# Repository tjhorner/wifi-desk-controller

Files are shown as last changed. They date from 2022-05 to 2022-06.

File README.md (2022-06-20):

# WiFi Desk Controller

This repository includes the source files for my WiFi Desk Controller design.

- `firmware`: The stock ESPHome-based firmware that's available from the GitHub Releases and [my website](https://shop.horner.tj/things/desk-controller/setup/stock)
- `enclosure`: Fusion 360 source, STL, and STEP files for the 3D-printable enclosure
- `pcb`: KiCad project files for the PCB

You may also find the associated [ESPHome custom component](https://github.com/tjhorner/esphome-standing-desk) interesting if you want to implement your own desk brand, or just dive deeper into how the firmware works.

## Stock Firmware

The stock firmware is ESPHome-based, and contains a bunch of components that are useful for setup. It exposes these entities:

- Desk Height: reports desk height as reported by control box
- Target Desk Height: changes the target desk height
- Desk Preset 1: sets the desk height to preset 1
- Desk Preset 2: sets the desk height to preset 2
- Desk Preset 3: sets the desk height to preset 3
- Desk Preset 4: sets the desk height to preset 4

The stock firmware is automatically built for each supported desk on release. There is a [GitHub Actions workflow](.github/workflows/build.yaml) which handles this. The `make-stock-bin` script replaces the `DESK_BRAND` in the [stock config.yaml](firmware/config.yaml) with the appropriate config and builds it. It runs this script for each of the supported desk brands in the build matrix, then uploads a release artifact.

If you would like to contribute compatibility for a new desk, you first need to submit a pull request to [this repo](https://github.com/tjhorner/esphome-standing-desk/tree/master/configs/desks) which adds a config file for the desk (and, if necessary, a new protocol decoder for it). See [Desk Compatibility](https://github.com/tjhorner/wifi-desk-controller/wiki/Desk-Compatibility) for more info on adding a new desk brand.

## License

The ESPHome configs are licensed under MIT; everything else (enclosure and PCB design) are CC BY-NC-SA 4.0. The appropriate license files are available in the root of the repo.

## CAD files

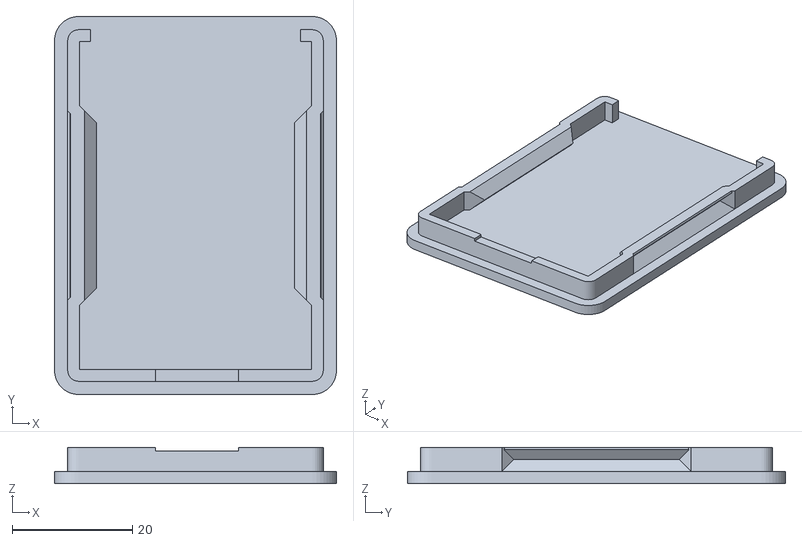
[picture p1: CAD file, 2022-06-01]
enclosure/enclosure_cover.stl
47.0 x 63.0 x 6.00

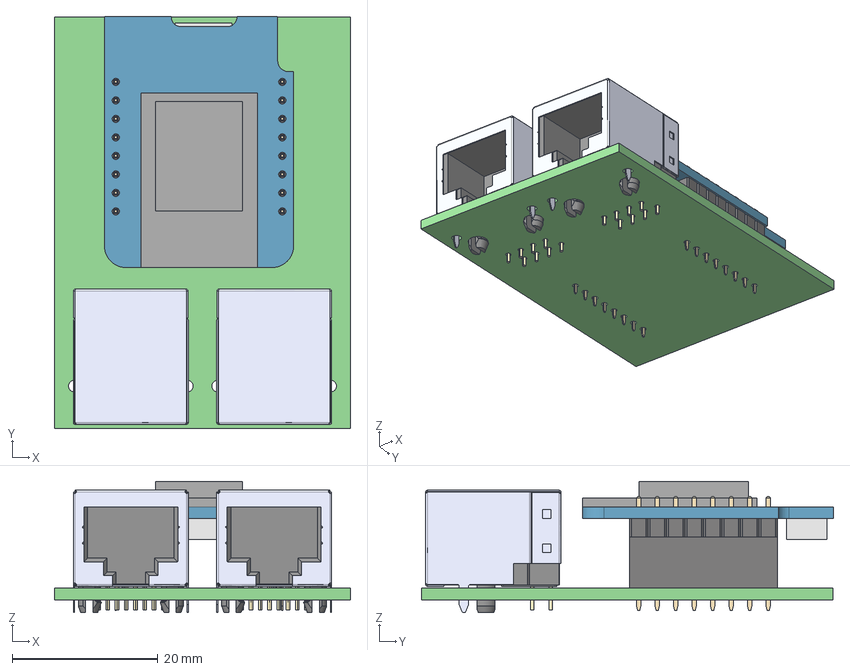
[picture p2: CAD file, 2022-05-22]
pcb/deskcontroller.step
40.6 x 56.6 x 18.0 mm
deskcontroller PCB

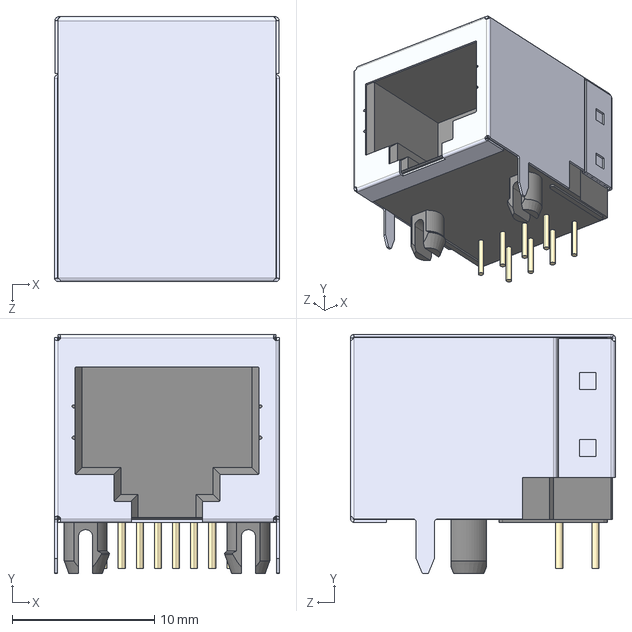
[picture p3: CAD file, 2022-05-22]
pcb/footprints/A-2004-2-4-LPS-N-R.step
15.8 x 16.8 x 18.6 mm

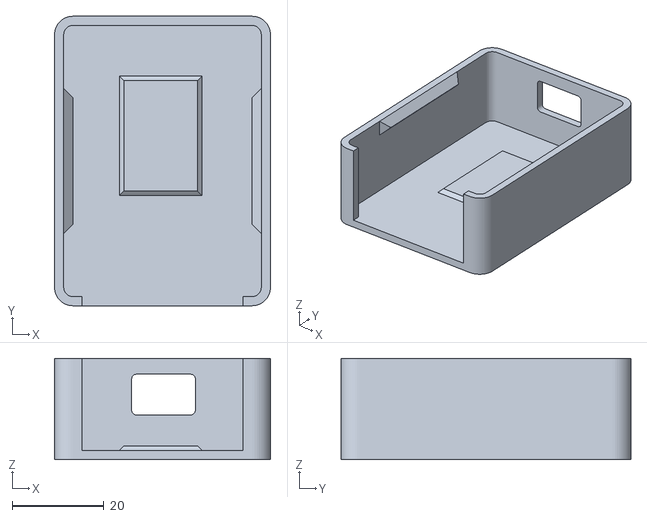
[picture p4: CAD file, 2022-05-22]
enclosure/enclosure_case.stl
47.0 x 63.0 x 22.0

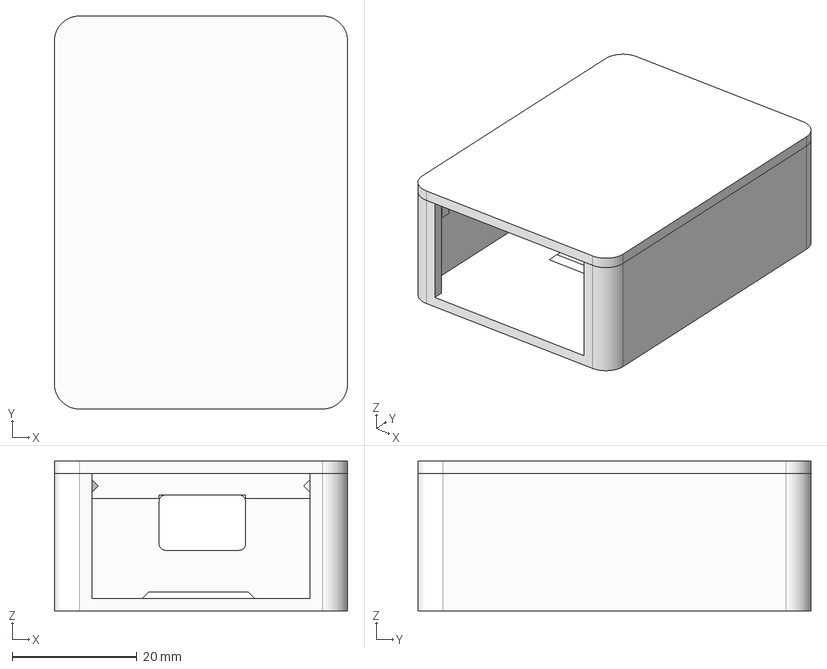
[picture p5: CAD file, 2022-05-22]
enclosure/enclosure.step
47.0 x 63.0 x 24.0 mm
Case
Top Cover

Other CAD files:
enclosure/enclosure.f3z

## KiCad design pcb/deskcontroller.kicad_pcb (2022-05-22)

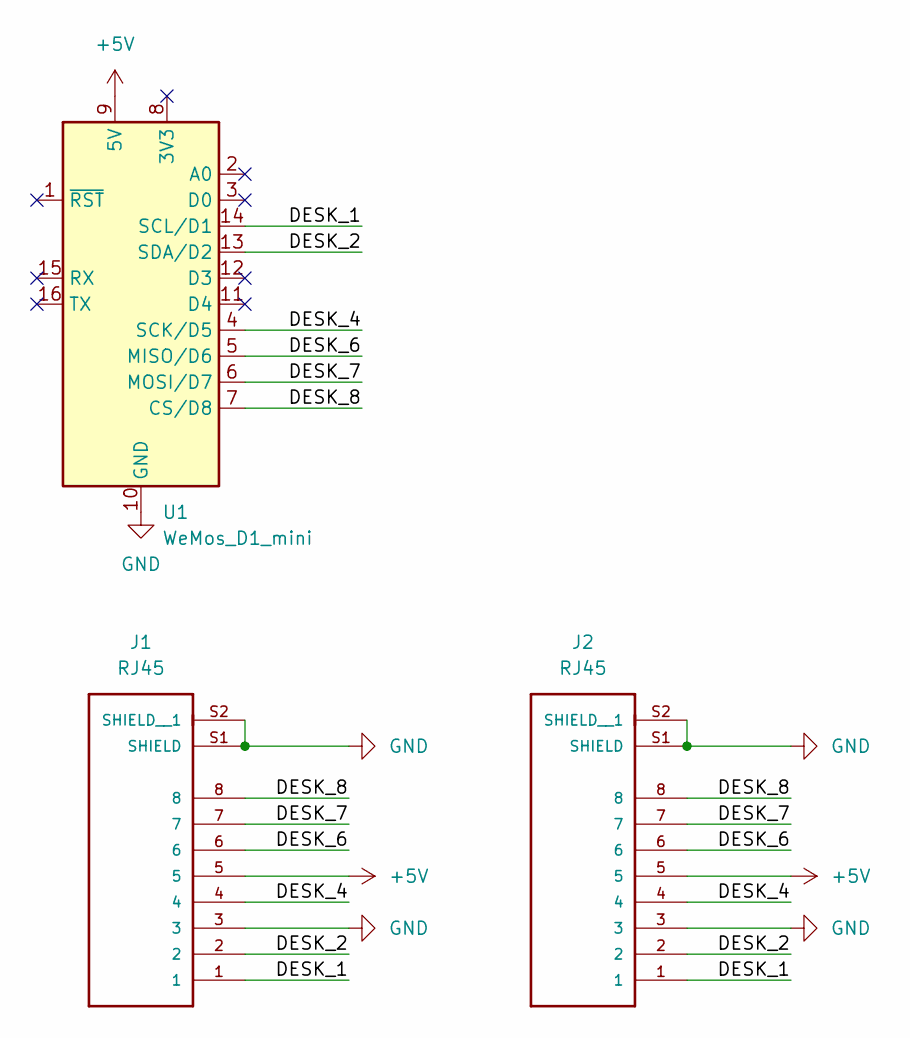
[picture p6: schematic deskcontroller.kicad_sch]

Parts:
J1, J2: RJ45; ASSMANN_A-2004-2-4-LPS-N-R; PARTREV 00
U1: WeMos_D1_mini; WEMOS_D1_mini_light

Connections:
+5V: J1.5, J2.5, U1.9 (5V)
/DESK_1: J1.1, J2.1, U1.14 (SCL/D1)
/DESK_2: J1.2, J2.2, U1.13 (SDA/D2)
/DESK_4: J1.4, J2.4, U1.4 (SCK/D5)
/DESK_6: J1.6, J2.6, U1.5 (MISO/D6)
/DESK_7: J1.7, J2.7, U1.6 (MOSI/D7)
/DESK_8: J1.8, J2.8, U1.7 (CS/D8)
GND: J1.3, J1.S1 (SHIELD), J1.S2 (SHIELD__1), J2.3, J2.S1 (SHIELD), J2.S2 (SHIELD__1), U1.10 (GND)

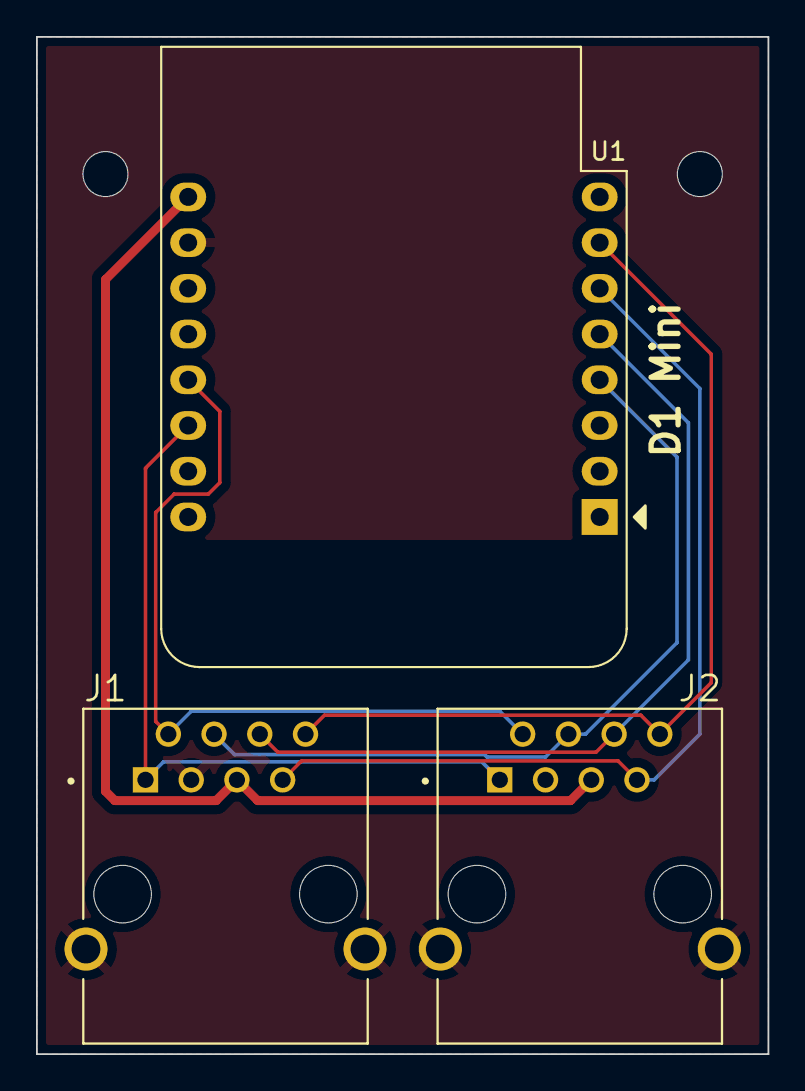
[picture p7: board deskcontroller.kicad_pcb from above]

Board: 2 copper layers, 40.6 x 56.5 mm, 3 parts (0 on the bottom side), 8 nets.

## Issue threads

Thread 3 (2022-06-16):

Board v2 Feature: Pinout Switching

tjhorner, 2022-06-16:
In v1 of the board, the pinouts are fixed, which means that desks must provide +5V on pin 5 and GND on pin 3. Some desks do not have these pins in the proper place, which means they are entirely incompatible without some cable-splicing hackery. For v2, I would like to add some way to change the RJ45 pins that these two power lines live on post-manufacturing, so that other formerly-incompatible desks could be used without any physical changes.

Currently I am thinking of implementing this with some DIP switches — one to dictate the +5V line, and the other to dictate the GND line. Progress on this feature will be tracked in this issue.

tjhorner, 2022-06-25:
After looking into this, it seems like it's not a very easy task. I think it would be better to make different versions of the board with common pinouts, because there can only be, what, like three different pinouts? Four? So let's see if we can gather enough data on those and I can make variations of the PCB for that

matthewfcarlson, 2022-09-26:
I'd look into jumper pads. Sparkfun uses them all the time to be able to configure their boards with different voltages. You'd just need really good documentation to make sure you don't short 5v to GND

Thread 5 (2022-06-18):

Support for Presets

rohankapoorcom, 2022-06-18:
Hi TJ,

Is it possible for you to add functionality for programming and recalling presets for desks that support that?

Thanks!

tjhorner, 2022-06-18:
Yes, definitely possible, just haven't gotten around to it yet. I will plan this for a future version of the firmware.

rohankapoorcom, 2022-06-18:
Awesome! I'm trying to avoid manually keeping the scenes in Home Assistant in sync with the desk so it's easier if the preset is directly exposed from the desk as a scene in Home Assistant.

rohankapoorcom, 2022-06-20:
I have an Uplift V2 (but I don't have my desk controller board yet, ordered it from your tindie store last week).

tjhorner, 2022-06-20:
I just added support for recalling presets in the 0.1.1 release. I'm not sure how I would add support for programming presets, but that doesn't sound like a very common use case to me, since it's a very one-and-done type of thing. If you need support for this I can open another issue

rohankapoorcom, 2022-06-23:
Awesome! I got my controller today and tested it out and it works great. Thanks so much!

tjhorner, 2022-06-23:
Glad to hear it! Let me know if you need anything else 👍

Closed 2022-06-20.

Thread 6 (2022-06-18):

Jarvis desks do not power up correctly without external power

tjhorner, 2022-06-18:
As discussed in #4, Jarvis desks have some issues with the v1 board that can be resolved but only temporarily and hackily.

I want to fix this issue in v2 of the board. Since I'm probably going to use an ESP32 module instead of a D1 Mini, this will be solved by using a GPIO pin that isn't attached to any other function of the chip.

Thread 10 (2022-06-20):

Board v2 Feature: USB-C Port

tjhorner, 2022-06-20:
Instead of the current D1 Mini which supplies the Micro USB port, I would like to include a USB-C port, mostly because it is cool, but also because USB-C devices are becoming ubiquitous and people probably have a lot of USB-C cables lying around.

Closed 2022-08-26.

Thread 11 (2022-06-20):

Board v2 Feature: ESP32

tjhorner, 2022-06-20:
For v2, I would like to use an ESP32-WROOM instead of the ESP8266 module on the D1 Mini, which would provide a lot of material benefits:

- It would make #6 pretty trivial to solve
- There are more GPIO pins to work with
- It has multiple hardware UARTs, so we can use that for communication with the desk
- The ESP32 is generally a beefier chip, giving us wiggle room for slightly unoptimized code or whatever

Closed 2022-08-26.

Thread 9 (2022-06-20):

v2 Enclosure Improvements

tjhorner, 2022-06-20:
This meta-issue will track all the minor improvements (i.e., things that are not big enough to warrant their own issue) planned to the enclosure design in v2

- [x] Flush RJ45 jacks
- [x] Flush USB-C port (also see #10)
- [x] Standoffs/screw mount (instead of adhesive)

tjhorner, 2022-06-26:
Got an initial design ready to test, and printed out a STEP of the new PCB for fit checking. Works great!

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

Closed 2022-08-26.

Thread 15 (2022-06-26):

Target Desk Height does Not Update when using a preset

degan6, 2022-06-26:
First, this product is awesome and works so well.

I noticed that when I use a preset either from the control panel or in Home Assistant the target height does not update to the height of the preset.

This causes them to be out of sync when updating the height through the slider.

tjhorner, 2022-06-26:
Heya, glad you're enjoying it!

This is expected behavior, at least for now. The preset buttons just simulate literally pressing the associated preset on the physical keypad, and I don't believe the control box reports back what the stored preset is, so there's not really a way to update the target height sensor with the correct value in this case.

But I could be wrong! I will look into this a bit deeper and see if there is something I can do. Worst case I can just make it update the target height once the preset height has been reached.

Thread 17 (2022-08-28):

New Desk Request:  Integrate Flexispot

Nesslax, 2022-08-28:
### Desk Model

Flexispot

### Physical and Electrical Compatibility

- [X] Desk is physically compatible (uses RJ45)
- [ ] Desk is electrically compatible (+5V is on pin 5, GND is on pin 3)

### Firmware Compatibility

No, none of the stock firmwares work

### Reverse Engineering Work

https://github.com/grssmnn/ha-flexispot-standing-desk
Here is a project that can may help your project grow

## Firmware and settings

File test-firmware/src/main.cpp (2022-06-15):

#include <Arduino.h>

// These correspond to RJ45 pins 1-6
int pins_to_test[] = {
  D1,
  D2,
  D5,
  D6,
  D7,
  D8
};

void setup() {
  Serial.begin(9600);

#ifdef TEST_HOST
  Serial.println("Initializing test host...");

  for (int &pin : pins_to_test) {
    pinMode(pin, INPUT);
  }

  pinMode(LED_BUILTIN, OUTPUT);
  digitalWrite(LED_BUILTIN, HIGH);

  delay(100);

  for (int &pin : pins_to_test) {
    Serial.print("Waiting for pin ");
    Serial.print(pin);
    Serial.println();

    while (digitalRead(pin) == LOW) {
      delay(50);
    }

    digitalWrite(LED_BUILTIN, LOW);
    delay(100);
    digitalWrite(LED_BUILTIN, HIGH);
  }
#else
  Serial.println("Initializing test target...");

  for (int &pin : pins_to_test) {
    pinMode(pin, OUTPUT);
    digitalWrite(pin, LOW);
  }
#endif
}

void loop() {
#ifdef TEST_TARGET
  for (int &pin : pins_to_test) {
    Serial.print("Pulsing pin ");
    Serial.print(pin);
    Serial.println();

    digitalWrite(pin, HIGH);
    delay(1000);
    digitalWrite(pin, LOW);
  }
#endif
}
